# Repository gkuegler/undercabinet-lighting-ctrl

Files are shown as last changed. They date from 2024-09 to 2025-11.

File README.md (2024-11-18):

<!-- | Supported Targets | ESP32 | ESP32-C2 | ESP32-C3 | ESP32-C6 | ESP32-H2 | ESP32-P4 | ESP32-S2 | ESP32-S3 | -->
<!-- | ----------------- | ----- | -------- | -------- | -------- | -------- | -------- | -------- | -------- | -->
| Supported Targets: | ESP32 | ESP32-S3 |
| --- | --- | --- |

Uses ESP-IDF v5.2

# Kitchen Under Cabinet Lighting Controller
This controller mounts upside down underneath kitchen cabinets enables the undercabinet lighting to be turned on/off with with wave of a hand.
This is the source code for a gesture activated lighting controller which utilizes a HC-SR04 ultrasonic distance sensor.

This controller is designed to be mounted upside down underneath kitchen cabinets. It's compatible with 12-24VDC LEDs.

# 3D Printed Case
The custom case was designed in OnShape. See the link below for the project file.
https://cad.onshape.com/documents/ef51b7b650ada663375a7fe6/w/94d192bce853b8bb4785d228/e/2ec3751c0459ca22265b7e29

## Folder contents

ESP-IDF projects are built using CMake. 

Below is short explanation of remaining files in the project folder.
```
├── CMakeLists.txt
├── components (project libraries, see ESP-IDF for info on components)
├── kicad (project files for custom PCB)
├── main
│   ├── CMakeLists.txt
│   └── main.cpp (entry point)
└── README.md
```

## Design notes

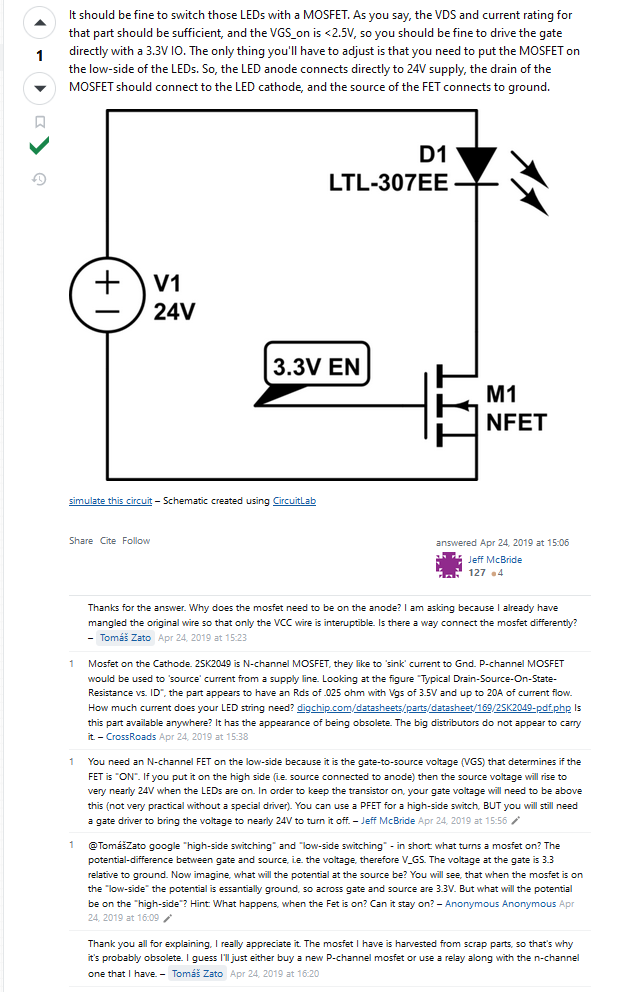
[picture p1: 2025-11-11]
design/n channel mosfet led switching.png

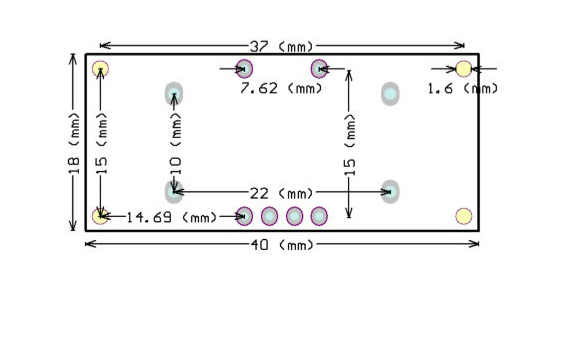
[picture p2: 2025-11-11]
design/Ultrasonic RCWL Dimensions.png

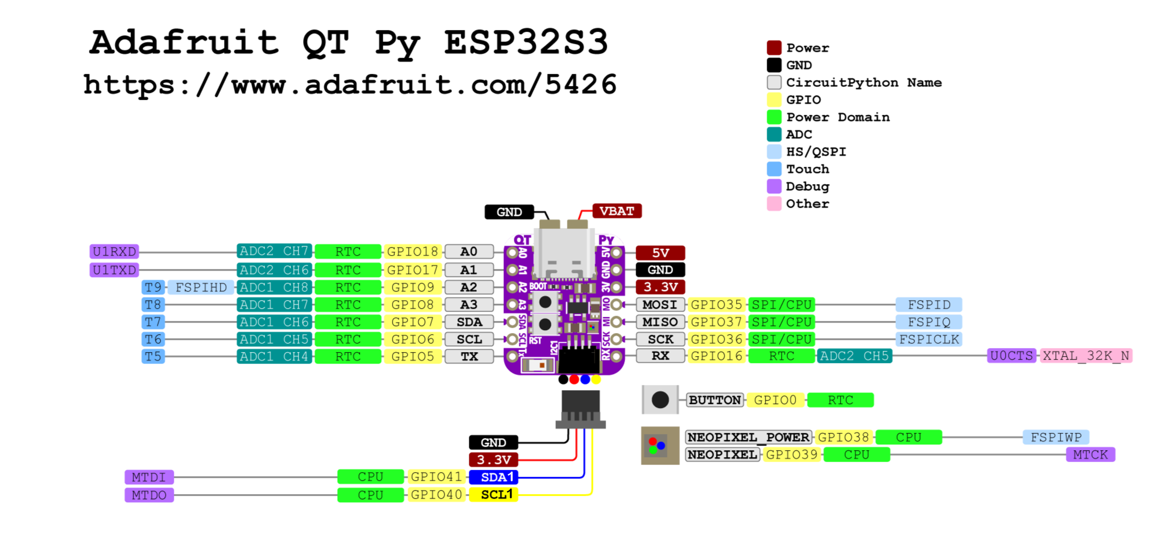
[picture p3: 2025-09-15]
design/Pinout Adafruit QTPy ESP32-S3.png

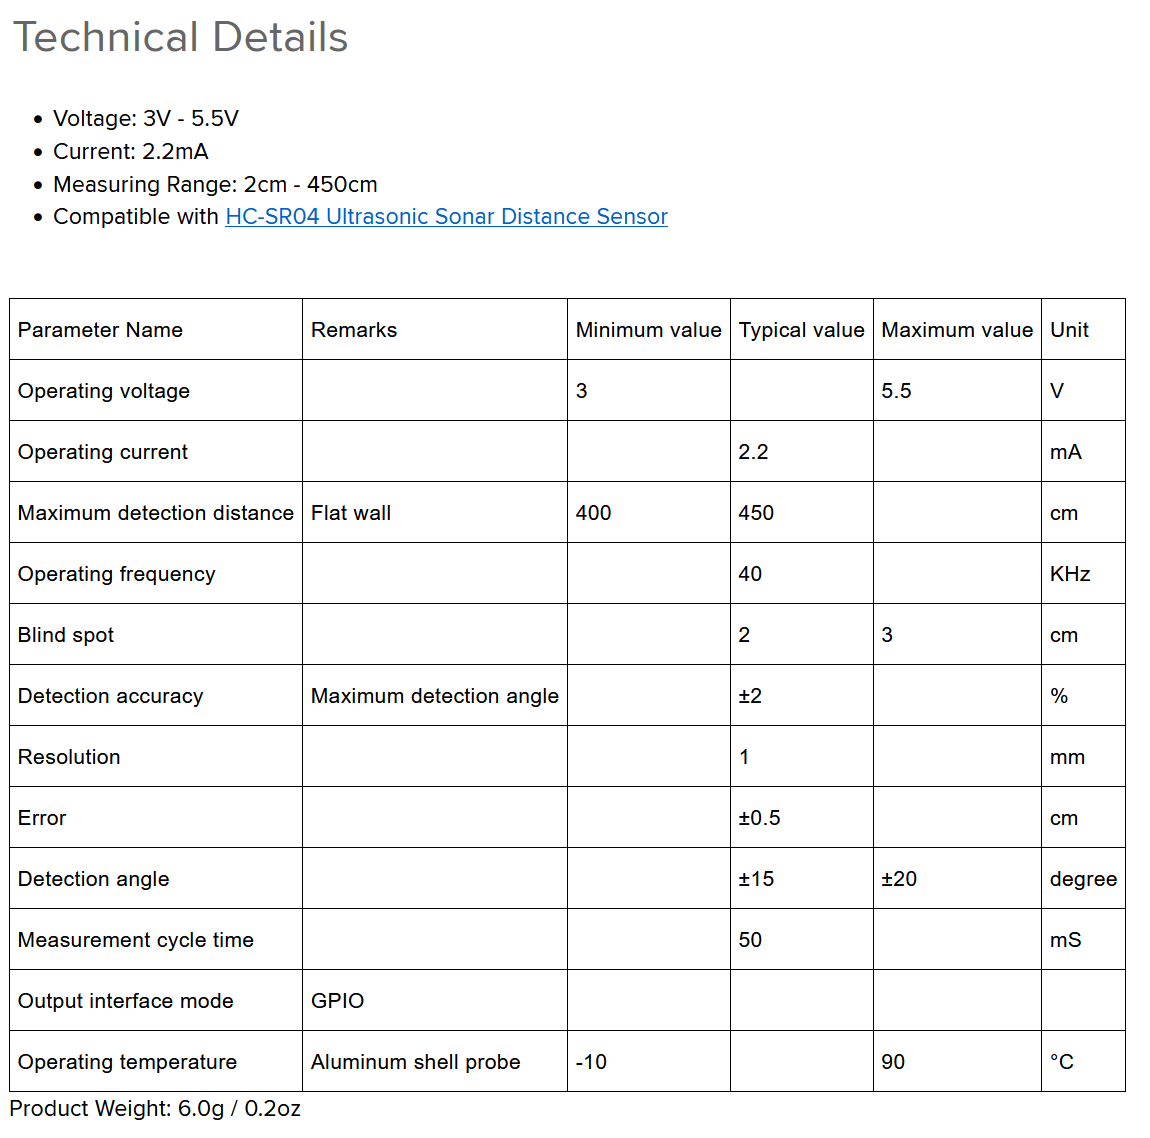
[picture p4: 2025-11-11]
design/Ultrasonic RCWL Specs.png

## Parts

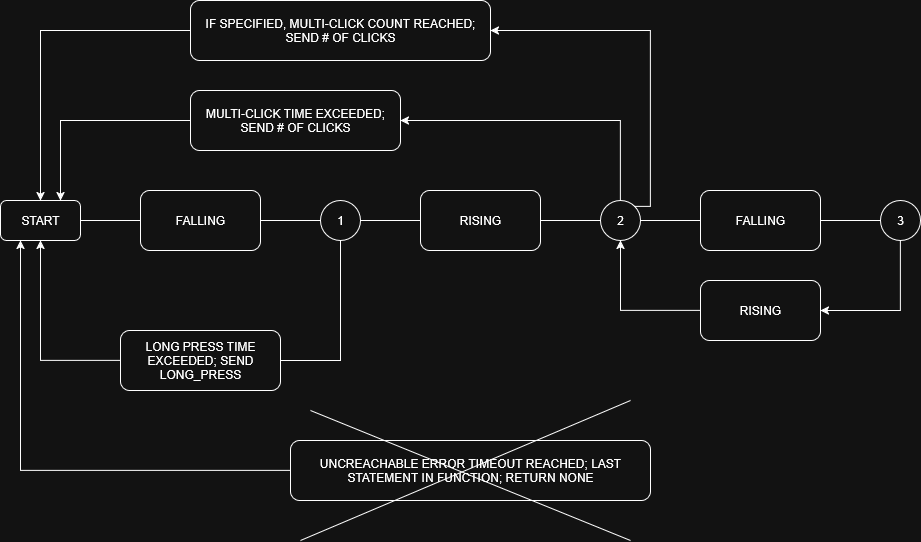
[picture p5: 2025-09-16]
components/debounce/button state machine.drawio.png

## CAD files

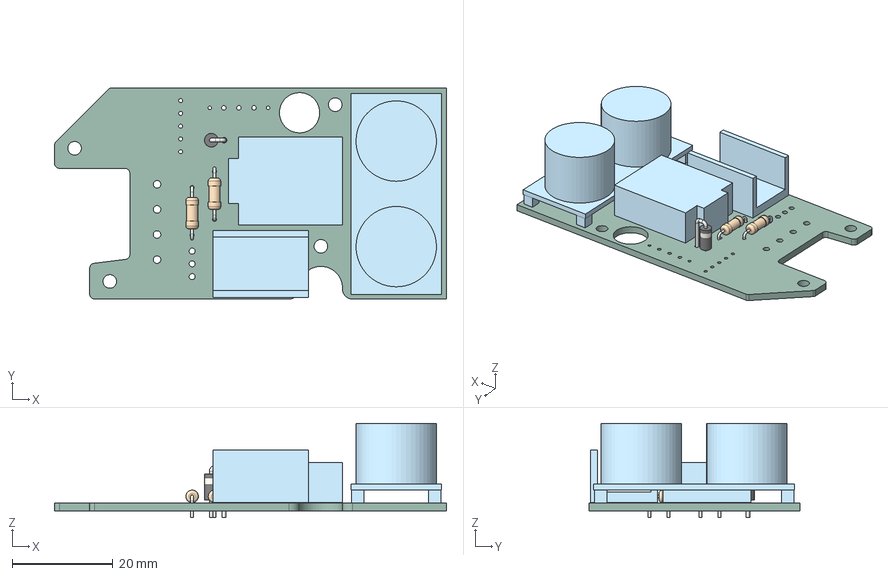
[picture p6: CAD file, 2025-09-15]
kicad/cablight-project v2.step
78.0 x 42.0 x 18.8 mm
R_Axial_DIN0207_L6.3mm_D2.5mm_P10.16mm_Horizontal x 2
QTPy
RCWL-1601
D_DO-41_SOD81_P2.54mm_Vertical_KathodeUp
TO-22-Heatsink
cablight-project_PCB

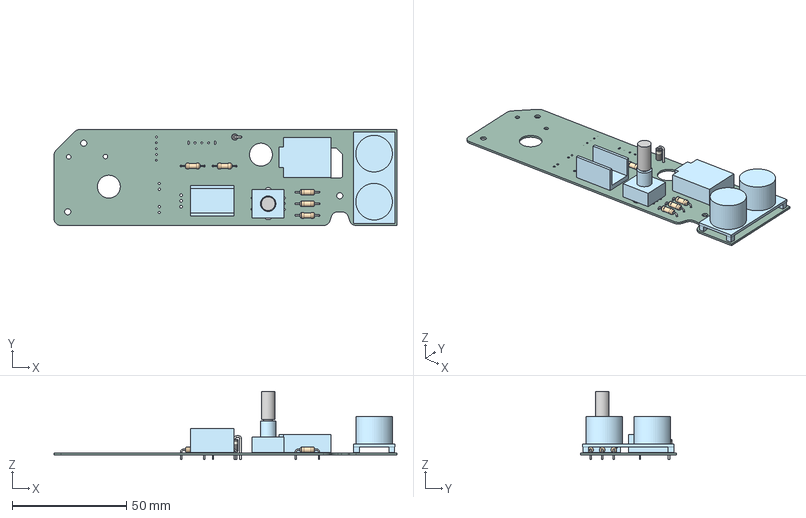
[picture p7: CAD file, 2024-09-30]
kicad/cablight-project/cablight-project.step
150.0 x 42.0 x 29.8 mm
R_Axial_DIN0207_L63mm_D25mm_P1016mm_Horizontal x 5
D_DO-41_SOD81_P2.54mm_Vertical_KathodeUp
cablight_PCB

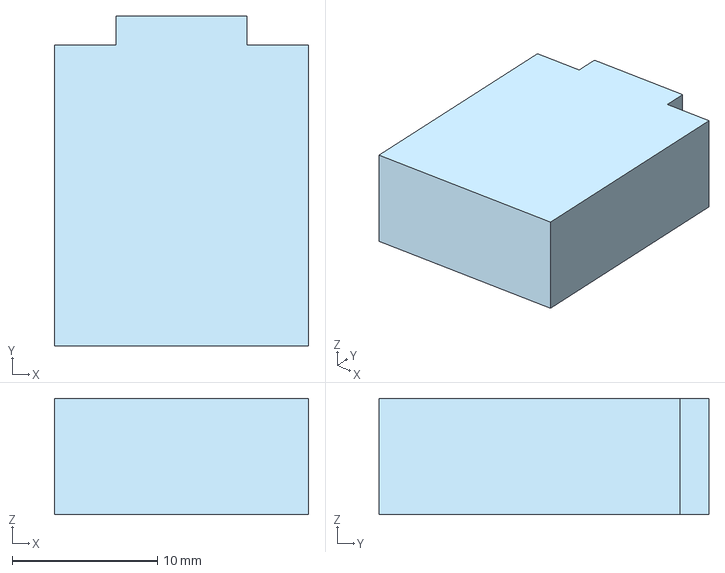
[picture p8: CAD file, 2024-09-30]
kicad/cablight-project/external part symbols, footprints & step files/Adafruit-QT-Py-ESP32-S3-PCB-main/QTPy.step
17.5 x 22.7 x 8.00 mm

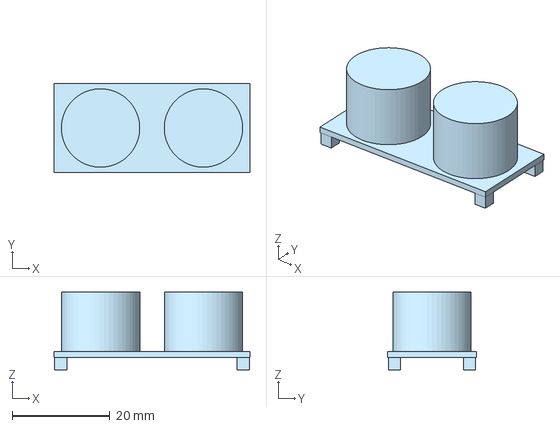
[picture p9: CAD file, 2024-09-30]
kicad/cablight-project/external part symbols, footprints & step files/RCWL-1601.step
40.0 x 18.1 x 15.8 mm

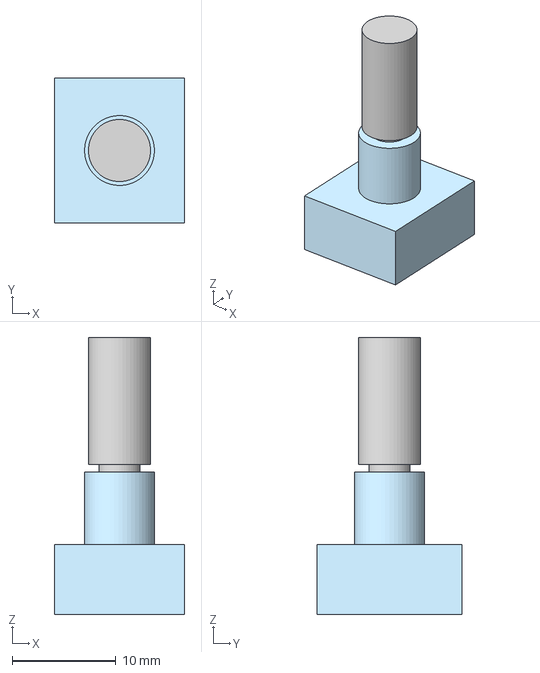
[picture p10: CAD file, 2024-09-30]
kicad/cablight-project/external part symbols, footprints & step files/rotary-encoder-PEC11R footprint/PEC11-20mm.step
12.6 x 14.0 x 26.8 mm

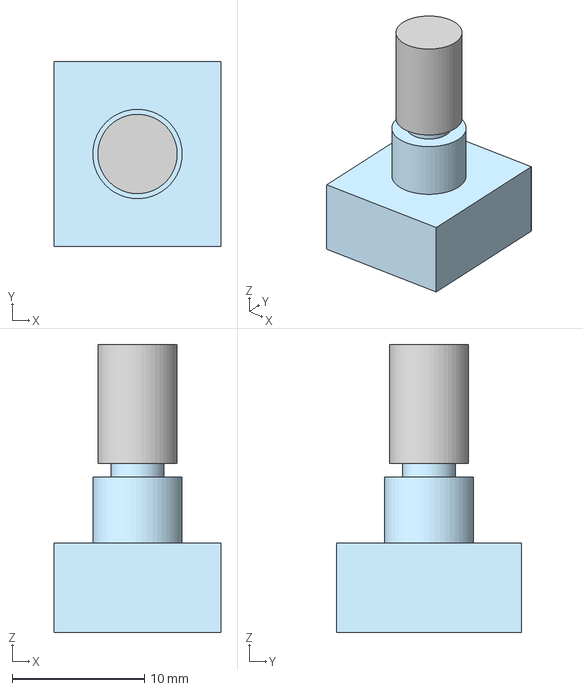
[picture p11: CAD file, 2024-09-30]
kicad/cablight-project/external part symbols, footprints & step files/rotary-encoder-PEC11R footprint/PEC11-15mm.step
12.6 x 14.0 x 21.8 mm

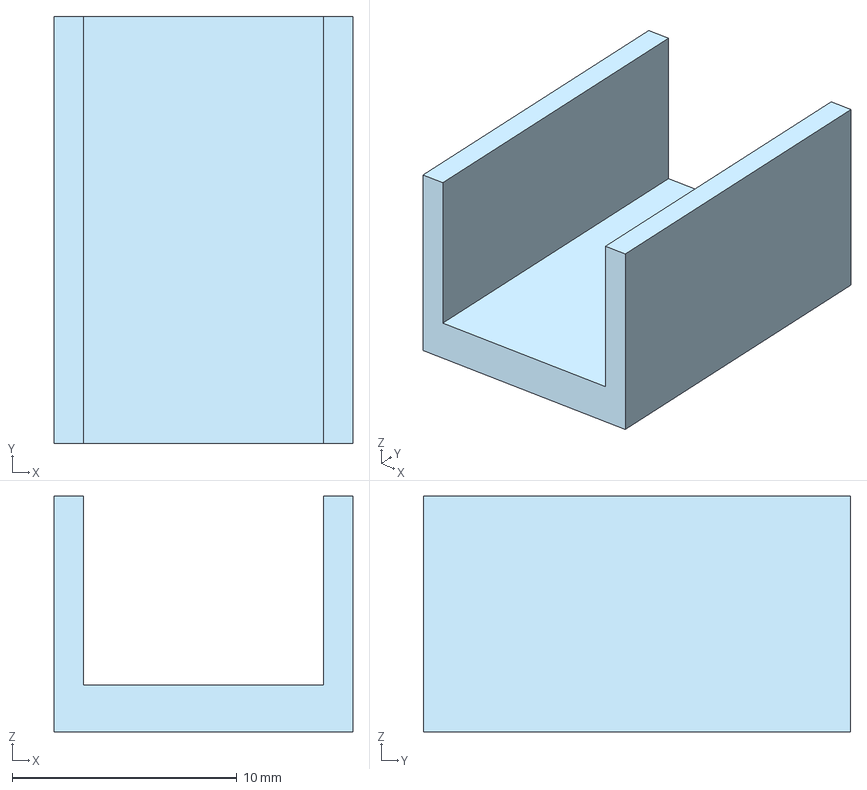
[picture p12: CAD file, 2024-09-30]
kicad/cablight-project/external part symbols, footprints & step files/TO-22-Heatsink.step
13.3 x 19.0 x 10.5 mm

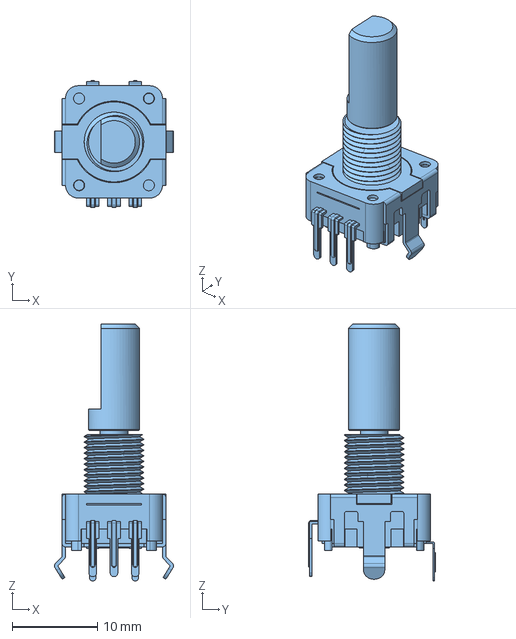
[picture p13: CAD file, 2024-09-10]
kicad/cablight-project/external part symbols, footprints & step files/rotary-encoder-PEC11R footprint/Bourns_-_PEC11R-4220F-S0024.step
14.0 x 14.9 x 30.2 mm

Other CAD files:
kicad/polycase option/C-0602.dwg
kicad/polycase option/BF-060210.dwg
kicad/cablight-project v2.stl

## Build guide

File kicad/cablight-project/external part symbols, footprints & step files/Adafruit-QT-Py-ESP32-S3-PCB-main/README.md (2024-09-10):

## Adafruit QT Py ESP32-S3 WiFi Dev Board PCB

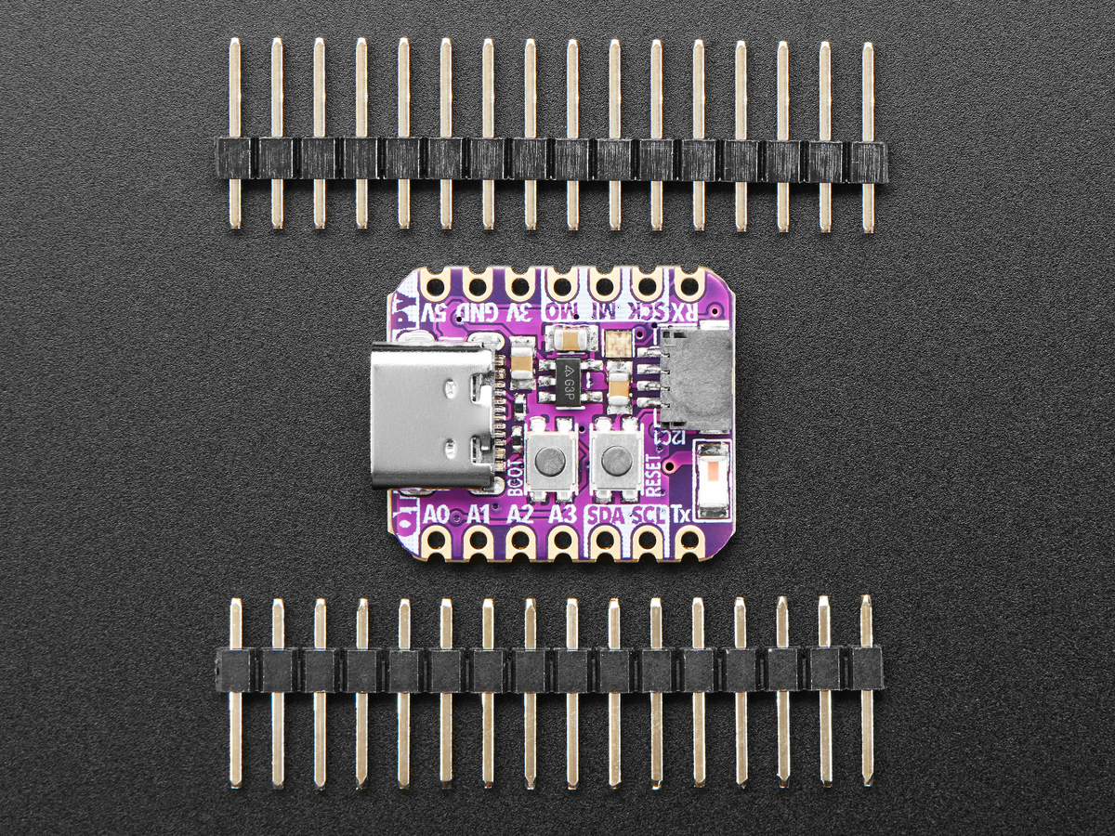
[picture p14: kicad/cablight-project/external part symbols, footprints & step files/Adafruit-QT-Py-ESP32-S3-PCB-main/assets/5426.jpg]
<a href="http://www.adafruit.com/products/5426"><br/>
Click here to purchase one from the Adafruit shop</a>

PCB files for the Adafruit QT Py ESP32-S3 WiFi Dev Board. 

Format is EagleCAD schematic and board layout
* https://www.adafruit.com/product/5426

### Description

The ESP32-S3 has arrived in QT Py format - and what a great way to get started with this powerful new chip from Espressif! With dual 240 MHz cores, WiFi and BLE support, and native USB, this QT Py is great for powering your IoT projects.

The ESP32-S3 is a highly-integrated, low-power, 2.4 GHz Wi-Fi System-on-Chip (SoC) solution that now has WiFi and BLE support, built-in native USB as well as some other interesting new technologies like Time of Flight distance measurements. With its state-of-the-art power and RF performance, this SoC is an ideal choice for a wide variety of application scenarios relating to the Internet of Things (IoT), wearable electronics, and smart homes. 

With native USB and 8 MB Flash this board will let you upgrade your existing ESP32 projects. Native USB means it can act like a keyboard or a disk drive, and no external USB-to-Serial converter required. WiFi and BLE mean it's awesome for IoT projects.

OLEDs! Inertial Measurement Units! Sensors a-plenty. All plug-and-play thanks to the innovative chainable design: SparkFun Qwiic-compatible STEMMA QT connectors for the I2C bus so you don't even need to solder! Just plug in a compatible cable and attach it to your MCU of choice, and you’re ready to load up some software and measure some light. Seeed Grove I2C boards will also work with this adapter cable.

Pinout and shape are Seeed Xiao compatible, with castellated pads so you can solder it flat to a PCB. In addition to the QT connector, we also added an RGB NeoPixel (with controllable power pin to allow for ultra-low-power usage), a reset button (great for restarting your program or entering the bootloader), and a button on GPIO 0 for entering the ROM bootloader or for user input

The ESP32-S3 has a dual-core 240 MHz chip, so it is comparable to ESP32's dual-core. However, there is no Bluetooth Classic support, only Bluetooth LE. This chip is a great step up from the earlier ESP32-S2! This ESP32-S3 chip we are using on the QT Py comes with 8 MB flash and no PSRAM, but it does have 512KB of SRAM so its fine for use with CircuitPython support as long as massive buffers are not needed. It's also great for use in ESP-IDF or with Arduino support.

* Same size, form-factor, and pin-out as Seeed Xiao
* USB Type C connector - If you have only Micro B cables, this adapter will come in handy!
* ESP32-S3 Dual Core 240MHz Tensilica processor - the next generation of ESP32-Sx, with native USB so it can act like a keyboard/mouse, MIDI device, disk drive, etc!
* Comes with 8MB Flash, 512KB SRAM, no PSRAM
* Native USB supported by every OS - can be used in Arduino or CircuitPython as USB serial console, MIDI, Keyboard/Mouse HID, even a little disk drive for storing Python scripts.
* Can be used with Arduino IDE or CircuitPython
* Built-in RGB NeoPixel LED with power control to reduce quiescent power in deep sleep
* Battery input pads on underside with diode protection for external battery packs up to 6V input
* 13 GPIO pins:
    * 11 on breakout pads, 2 more on QT connector
    * 10 x 12-bit analog inputs (SPI high speed pads do not have analog inputs)
    * PWM outputs on any pin
    * Two I2C ports, one on the breakout pads, and another with STEMMA QT plug-n-play connector
    * Hardware UART
    * Hardware SPI on the high speed SPI peripheral pins
    * Hardware I2S on any pins
    * 5 x Capacitive Touch with no additional components required
* 3.3V regulator with 600mA peak output
* Light sleep at 2~4mA, deep sleep at ~70uA
* Reset switch for starting your project code over, boot 0 button for entering bootloader mode
* Really really small

### License

Adafruit invests time and resources providing this open source design, please support Adafruit and open-source hardware by purchasing products from [Adafruit](https://www.adafruit.com)!

Designed by Limor Fried/Ladyada for Adafruit Industries.

Creative Commons Attribution/Share-Alike, all text above must be included in any redistribution. 
See license.txt for additional details.

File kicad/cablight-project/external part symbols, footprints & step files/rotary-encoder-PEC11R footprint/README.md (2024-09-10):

# Adafruit's PEC11R-4220F-S0024 Rotary encoder for KiCAD

### How to use this footprint
1. Download .zip file containing this repository's contents
2. Open the footprint editor



3. Right click on the in the footprint tree explorer and choose import footprint



4. Choose the edit footprint properties icon



5. Open the 3D models option in the edit footprint properties modal



6. Choose the "+" icon to add a new 3D model
7. Select the .step file downloaded from this repository
8. Validate the model's fitment on the footprint



9. Save footprint in the desired library



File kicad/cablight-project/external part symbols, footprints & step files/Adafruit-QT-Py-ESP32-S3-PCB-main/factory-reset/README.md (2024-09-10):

## Factory Reset file - QT ESP32-S3 WiFi Dev Board

This is the factory reset file for the QT ESP32-S3 WiFi Dev Board.

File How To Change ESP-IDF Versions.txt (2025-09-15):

1. Use express install for "workspace folder" to install ver version.
File hierarchy:

L:\Espressif
└──idf_v5.5.1  (make this folder for each version)
    ├── idf              (make this folder, choose as idf location)
    └── tools            (make this folder, choose as toolchain folder)

2.
a. Use a project sample to generate the required .vscode folder files.
b. ESP_IDF: Add VSCode Configuration folder (will add settings.json & launch.json)

--- settings.josn ---
Use options at bottom to select:
    - flashing method
    - com port
    - openocd target board (IDF_TARGET)

--- c_cpp_properties.json ---

Set this to the current toolchain version compiler (this will prevent include sq):
"compilerPath": "${config:idf.toolsPathWin}\\tools\\xtensa-esp-elf\\esp-14.2.0_20241119\\xtensa-esp-elf\\bin\\xtensa-esp32s3-elf-gcc.exe",

Add compiler commands:
"compileCommands": ["${workspaceFolder}/build/compile_commands.json"],

# Debugging
Download Zadig tool (Zadig_X.X.exe) from https://zadig.akeo.ie/ and run it.
Set (Interface 1) to libusbk. Don't touch (Interface 0 is serial port).
If I need to reset the driver for the serial port. Go to Device Manager. THen USB devices and update driver.

Set Adapter Speed in esp jtag config file in toolchain folder:
adapter speed 20000

In Zadig tool go to Options and check List All Devices.

Check the list of devices that should contain two specific USB entries:  (Interface 0) and  (Interface 1).

The first device ( (Interface 0)) is connected to the JTAG port of the ESP32. Original driver of this device should be replaced with WinUSB (v6xxxxx).

Note: Do not change the second device (Interface 1). It is routed to ESP32's serial port (UART) used for upload of application to ESP32's flash.

There are two versions of this board: 4MB Flash/2MB PSRAM or 8MB Flash/No PSRAM
I have (2) of the 4MB Flash/2MB PSRAM for the smaller QTPy's.

Make sure
"idf.openOcdDebugLevel": 1,
If it is set too high (like 4) things will take too long and it will error out.

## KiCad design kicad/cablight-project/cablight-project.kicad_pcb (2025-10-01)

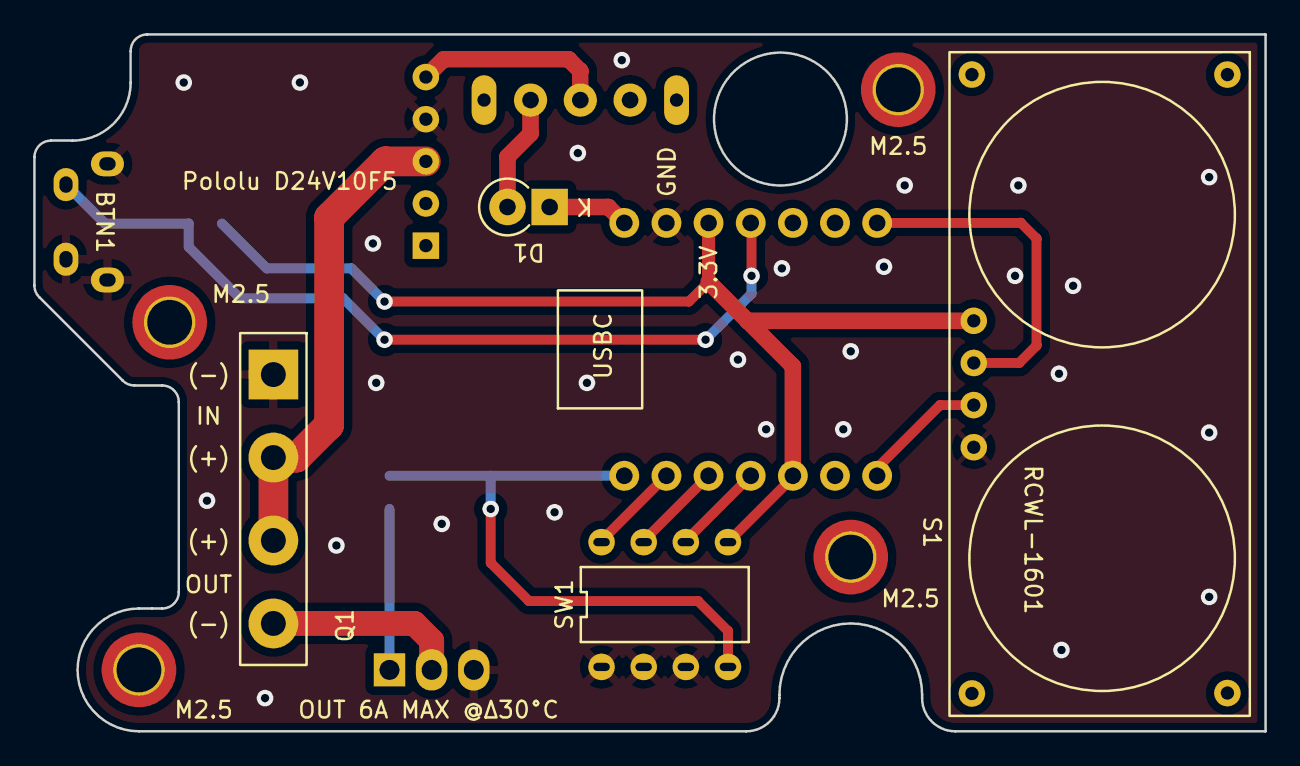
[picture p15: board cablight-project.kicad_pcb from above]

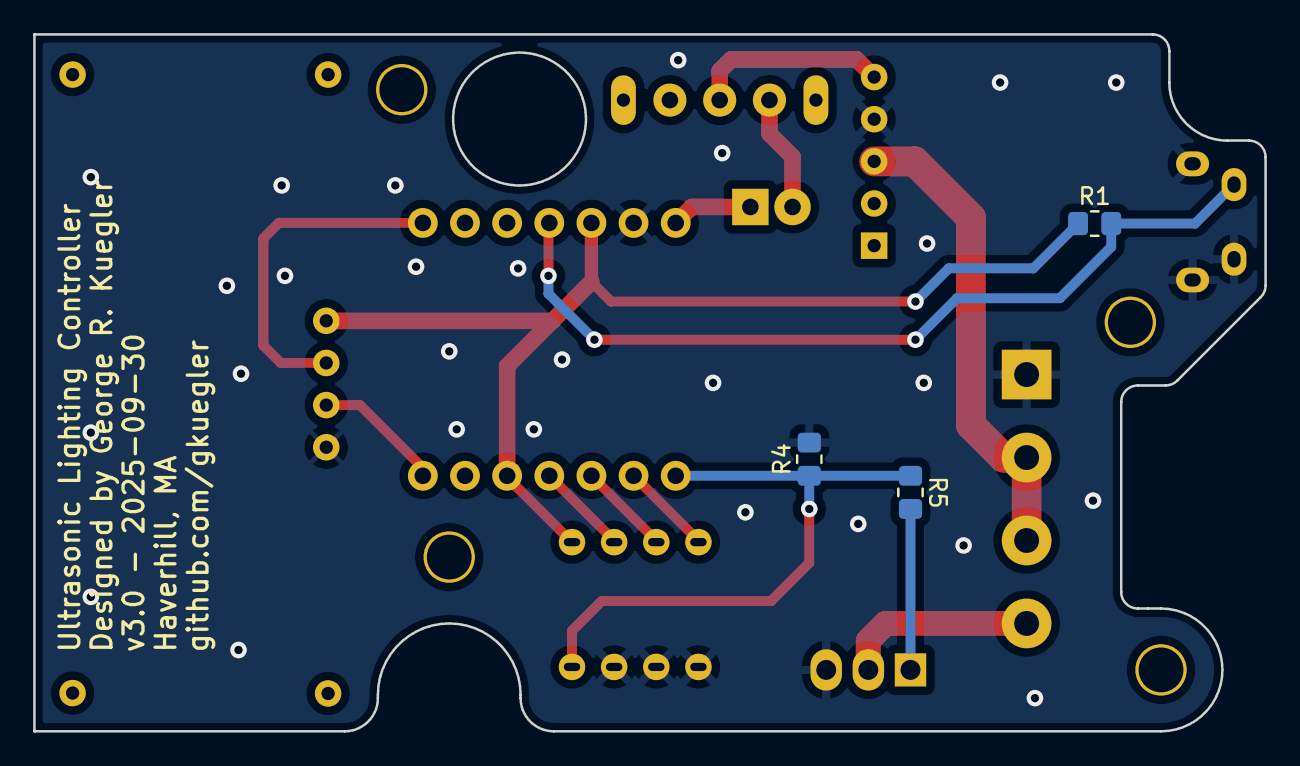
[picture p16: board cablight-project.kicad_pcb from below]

Board: 2 copper layers, 74.2 x 42.0 mm, 16 parts (3 on the bottom side), 15 nets.

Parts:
BTN1: SW_Push; Tactile Switch Wurth
D1: 1N5817; D_DO-41_SOD81_P2.54mm_Vertical_KathodeUp
J3: Screw_Term_1x4_5mm; Molex 4pin Terminal Block
M2.5, M2.5#2, M2.5#3, M2.5#4: MountingHole_2.7mm_M2.5_ISO7380_Pad_TopOnly
P1: Pololu D24V10F5; Pololu_5V_H
Q1: IRLB8721PBF; TO-220F-3_H_Heatsink
R1: 10k; R_0805_2012Metric_Pad1.20x1.40mm_HandSolder
R4: 10K; R_0805_2012Metric_Pad1.20x1.40mm_HandSolder
R5: 47R; R_0805_2012Metric_Pad1.20x1.40mm_HandSolder
S1: RCWL-1601
SW1: SW_DIP_x04; DIP-4 DS04-254 SAME SKY
SW3: switch_SPDT_SLW_121586; Switch_SPDT_CUI_500mA_3mm
U1: AdafruitQTPyEsp32S3

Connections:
/5V_MCU: D1.1 (K), U1.14 (5V)
/5V_sw: D1.2 (A), SW3.2
/+5V: P1.5 (VOUT_5V), SW3.1
/+24V: J3.2, J3.3, P1.3 (VIN_24V)
/LED-: J3.4, Q1.2 (D)
/SRO4 PWR: R1.1, S1.1 (Vin), SW1.5, U1.5 (GPIO_7), U1.12 (3.3V)
/echo: S1.3 (Echo), U1.7 (GPIO_5)
/trig: S1.2 (Trig), U1.8 (GPIO_16)
<NO NET>: BTN1.2, BTN1.GND, J3.1, P1.4 (GND), Q1.3 (S), R4.2, S1.4 (GND), SW1.1, SW1.2, SW1.3, U1.13 (GND)
unnamed: Q1.1 (G), R5.2
unnamed: SW1.6, U1.4 (GPIO_8)
unnamed: SW1.7, U1.3 (GPIO_9)
unnamed: SW1.8, U1.2 (GPIO_17)
unnamed: R4.1, R5.1, SW1.4, U1.1 (GPIO_18)
unnamed: BTN1.1, R1.2, U1.11 (GPIO_35)

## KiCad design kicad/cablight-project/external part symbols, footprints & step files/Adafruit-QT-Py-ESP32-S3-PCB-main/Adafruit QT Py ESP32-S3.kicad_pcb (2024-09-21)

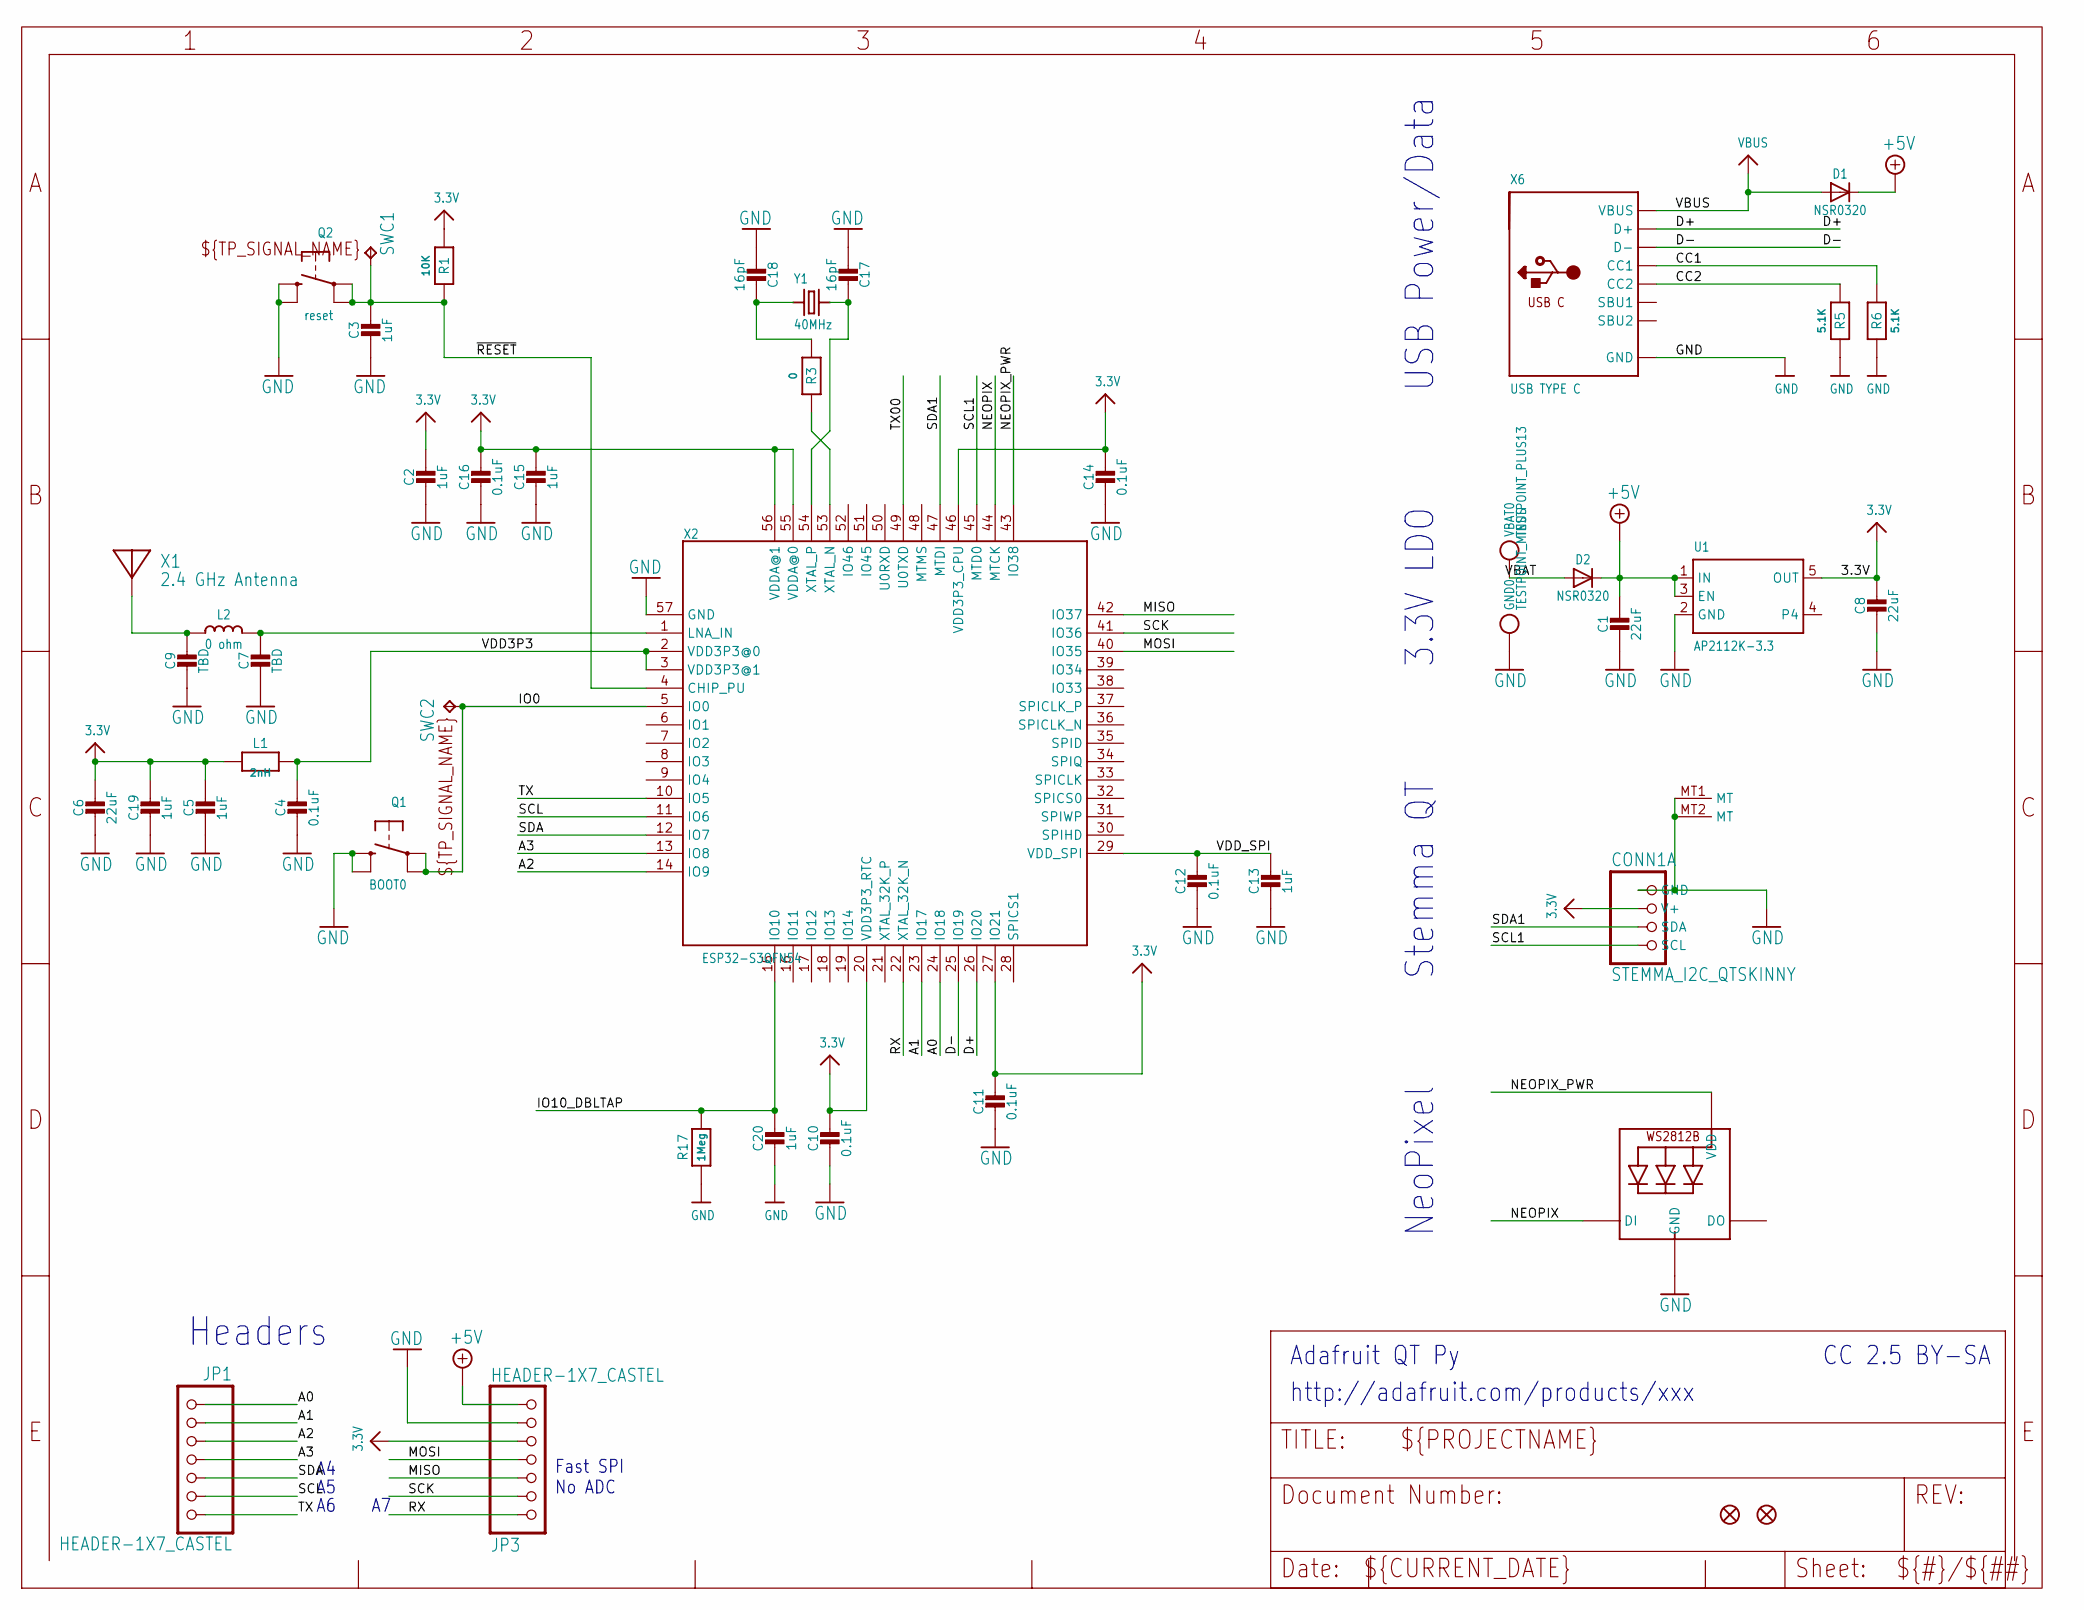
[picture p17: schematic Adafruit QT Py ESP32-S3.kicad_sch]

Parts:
C1, C6, C8: 22uF; 0805-NO
C2, C3, C5, C13, C15, C19, C20: 1uF; _0402NO
C4, C10, C11, C12, C14, C16: 0.1uF; _0402NO
C7, C9: TBD; _0402NO
C17, C18: 16pF; _0402NO
CONN1: STEMMA_I2C_QTSKINNY; JST_SH4_SKINNY
D1, D2: NSR0320; SOD-323_MINI
GND0: TESTPOINT_MINUS; TESTPOINT_MINUS_1X3MM
JP1, JP3: HEADER-1X7_CASTEL; 1X07_CASTEL
L1: 2nH; _0402NO
L2: 0 ohm; _0402
LED1: WS2812B_SK6805_1515; SK6805_1515
Q1: BOOT0; BTN_KMR2_4.6X2.8
Q2: reset; BTN_KMR2_4.6X2.8
R1: 10K; _0402NO
R3: 0; _0402NO
R5, R6: 5.1K; _0402NO
R17: 1Meg; _0402NO
SWC1, SWC2: TPB1,27; B1,27
U1: AP2112K-3.3; SOT23-5
U$6, U$8: FIDUCIAL_1MM
VBAT0: TESTPOINT_PLUS13; TESTPOINT_PLUS_1X3MM
X1: 2.4 GHz Antenna; ANT_2450AT18B100
X2: ESP32-S3QFN54; QFN56_7X7
X6: USB TYPE C; USB_C_CUSB31-CFM2AX-01-X
Y1: 40MHz; CRYSTAL_2X1.6

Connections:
3.3V: C2.1, C5.1, C6.1, C8.1, C10.1, C11.1, C14.1, C15.1, C16.1, C19.1, CONN1.2 (V+), JP3.5, JP3.5C (5), L1.1, R1.1, U1.5 (OUT), X2.20 (VDD3P3_RTC), X2.27 (IO21), X2.46 (VDD3P3_CPU), X2.55 (VDDA@0), X2.56 (VDDA@1)
+5V: C1.1, D1.C, D2.C, JP3.7, JP3.7C (7), U1.1 (IN), U1.3 (EN)
A0: JP1.1, JP1.1C (1), X2.24 (IO18)
A1: JP1.2, JP1.2C (2), X2.23 (IO17)
A2: JP1.3, JP1.3C (3), X2.14 (IO9)
A3: JP1.4, JP1.4C (4), X2.13 (IO8)
CC1: R6.2, X6.A5 (CC1)
CC2: R5.2, X6.B5 (CC2)
D+: X2.26 (IO20), X6.A6 (D+), X6.B6 (D+)
D-: X2.25 (IO19), X6.A7 (D-), X6.B7 (D-)
GND: C1.2, C2.2, C3.2, C4.2, C5.2, C6.2, C7.2, C8.2, C9.2, C10.2, C11.2, C12.2, C13.2, C14.2, C15.2, C16.2, C17.2, C18.2, C19.2, C20.2, CONN1.1 (GND), CONN1.MT1 (MT), CONN1.MT2 (MT), GND0.P$1, JP3.6, JP3.6C (6), LED1.4 (GND), Q1.B (S), Q1.B' (S1), Q2.B (S), Q2.B' (S1), R5.1, R6.1, R17.1, U1.2 (GND), X2.57 (GND), X6.A1B12 (GND), X6.B1A12 (GND)
IO0: Q1.A, Q1.A' (P1), SWC2.TP, X2.5 (IO0)
IO10_DBLTAP: C20.1, R17.2, X2.15 (IO10)
MISO: JP3.3, JP3.3C (3), X2.42 (IO37)
MOSI: JP3.4, JP3.4C (4), X2.40 (IO35)
unnamed: R3.2, X2.53 (XTAL_N)
unnamed: C7.1, L2.2, X2.1 (LNA_IN)
unnamed: C9.1, L2.1, X1.FP
unnamed: C17.1, X2.54 (XTAL_P), Y1.3 (2)
unnamed: C18.1, R3.1, Y1.1
NEOPIX: LED1.1 (DI), X2.44 (MTCK)
NEOPIX_PWR: LED1.2 (VDD), X2.43 (IO38)
RX: JP3.1, JP3.1C (1), X2.22 (XTAL_32K_N)
SCK: JP3.2, JP3.2C (2), X2.41 (IO36)
SCL: JP1.6, JP1.6C (6), X2.11 (IO6)
SCL1: CONN1.4 (SCL), X2.45 (MTD0)
SDA: JP1.5, JP1.5C (5), X2.12 (IO7)
SDA1: CONN1.3 (SDA), X2.47 (MTDI)
TX: JP1.7, JP1.7C (7), X2.10 (IO5)
TX00: X2.49 (U0TXD)
VBAT: D2.A, VBAT0.P$1
VBUS: D1.A, X6.A4B9 (VBUS), X6.B4A9 (VBUS)
VDD3P3: C4.1, L1.2, X2.2 (VDD3P3@0), X2.3 (VDD3P3@1)
VDD_SPI: C12.1, C13.1, X2.29 (VDD_SPI)
~RESET: C3.1, Q2.A, Q2.A' (P1), R1.2, SWC1.TP, X2.4 (CHIP_PU)

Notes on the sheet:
USB Power/Data
CC 2.5 BY-SA
Fast SPI No ADC
NeoPixel
Stemma QT
Adafruit QT Py
Headers
http://adafruit.com/products/xxx
3.3V LDO

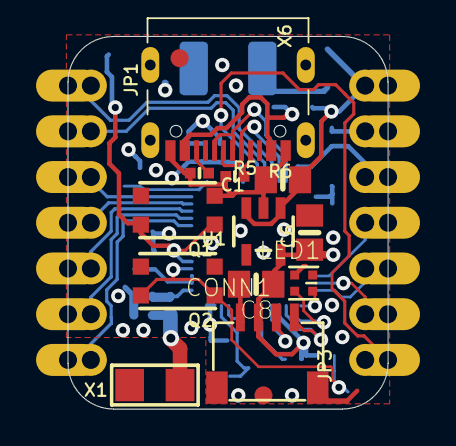
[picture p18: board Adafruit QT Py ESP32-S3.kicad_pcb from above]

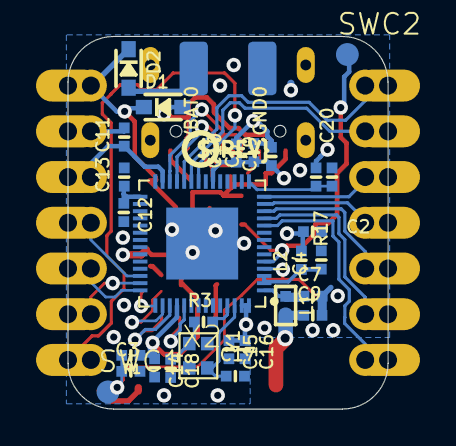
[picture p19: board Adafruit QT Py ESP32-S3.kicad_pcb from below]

Board: 4 copper layers, 17.8 x 20.7 mm, 49 parts (32 on the bottom side), 34 nets.

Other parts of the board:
U$7: QTPY_ESP32_TOP
U$11: QTPYS3_BOT
U$12: PCBFEAT-REV-040

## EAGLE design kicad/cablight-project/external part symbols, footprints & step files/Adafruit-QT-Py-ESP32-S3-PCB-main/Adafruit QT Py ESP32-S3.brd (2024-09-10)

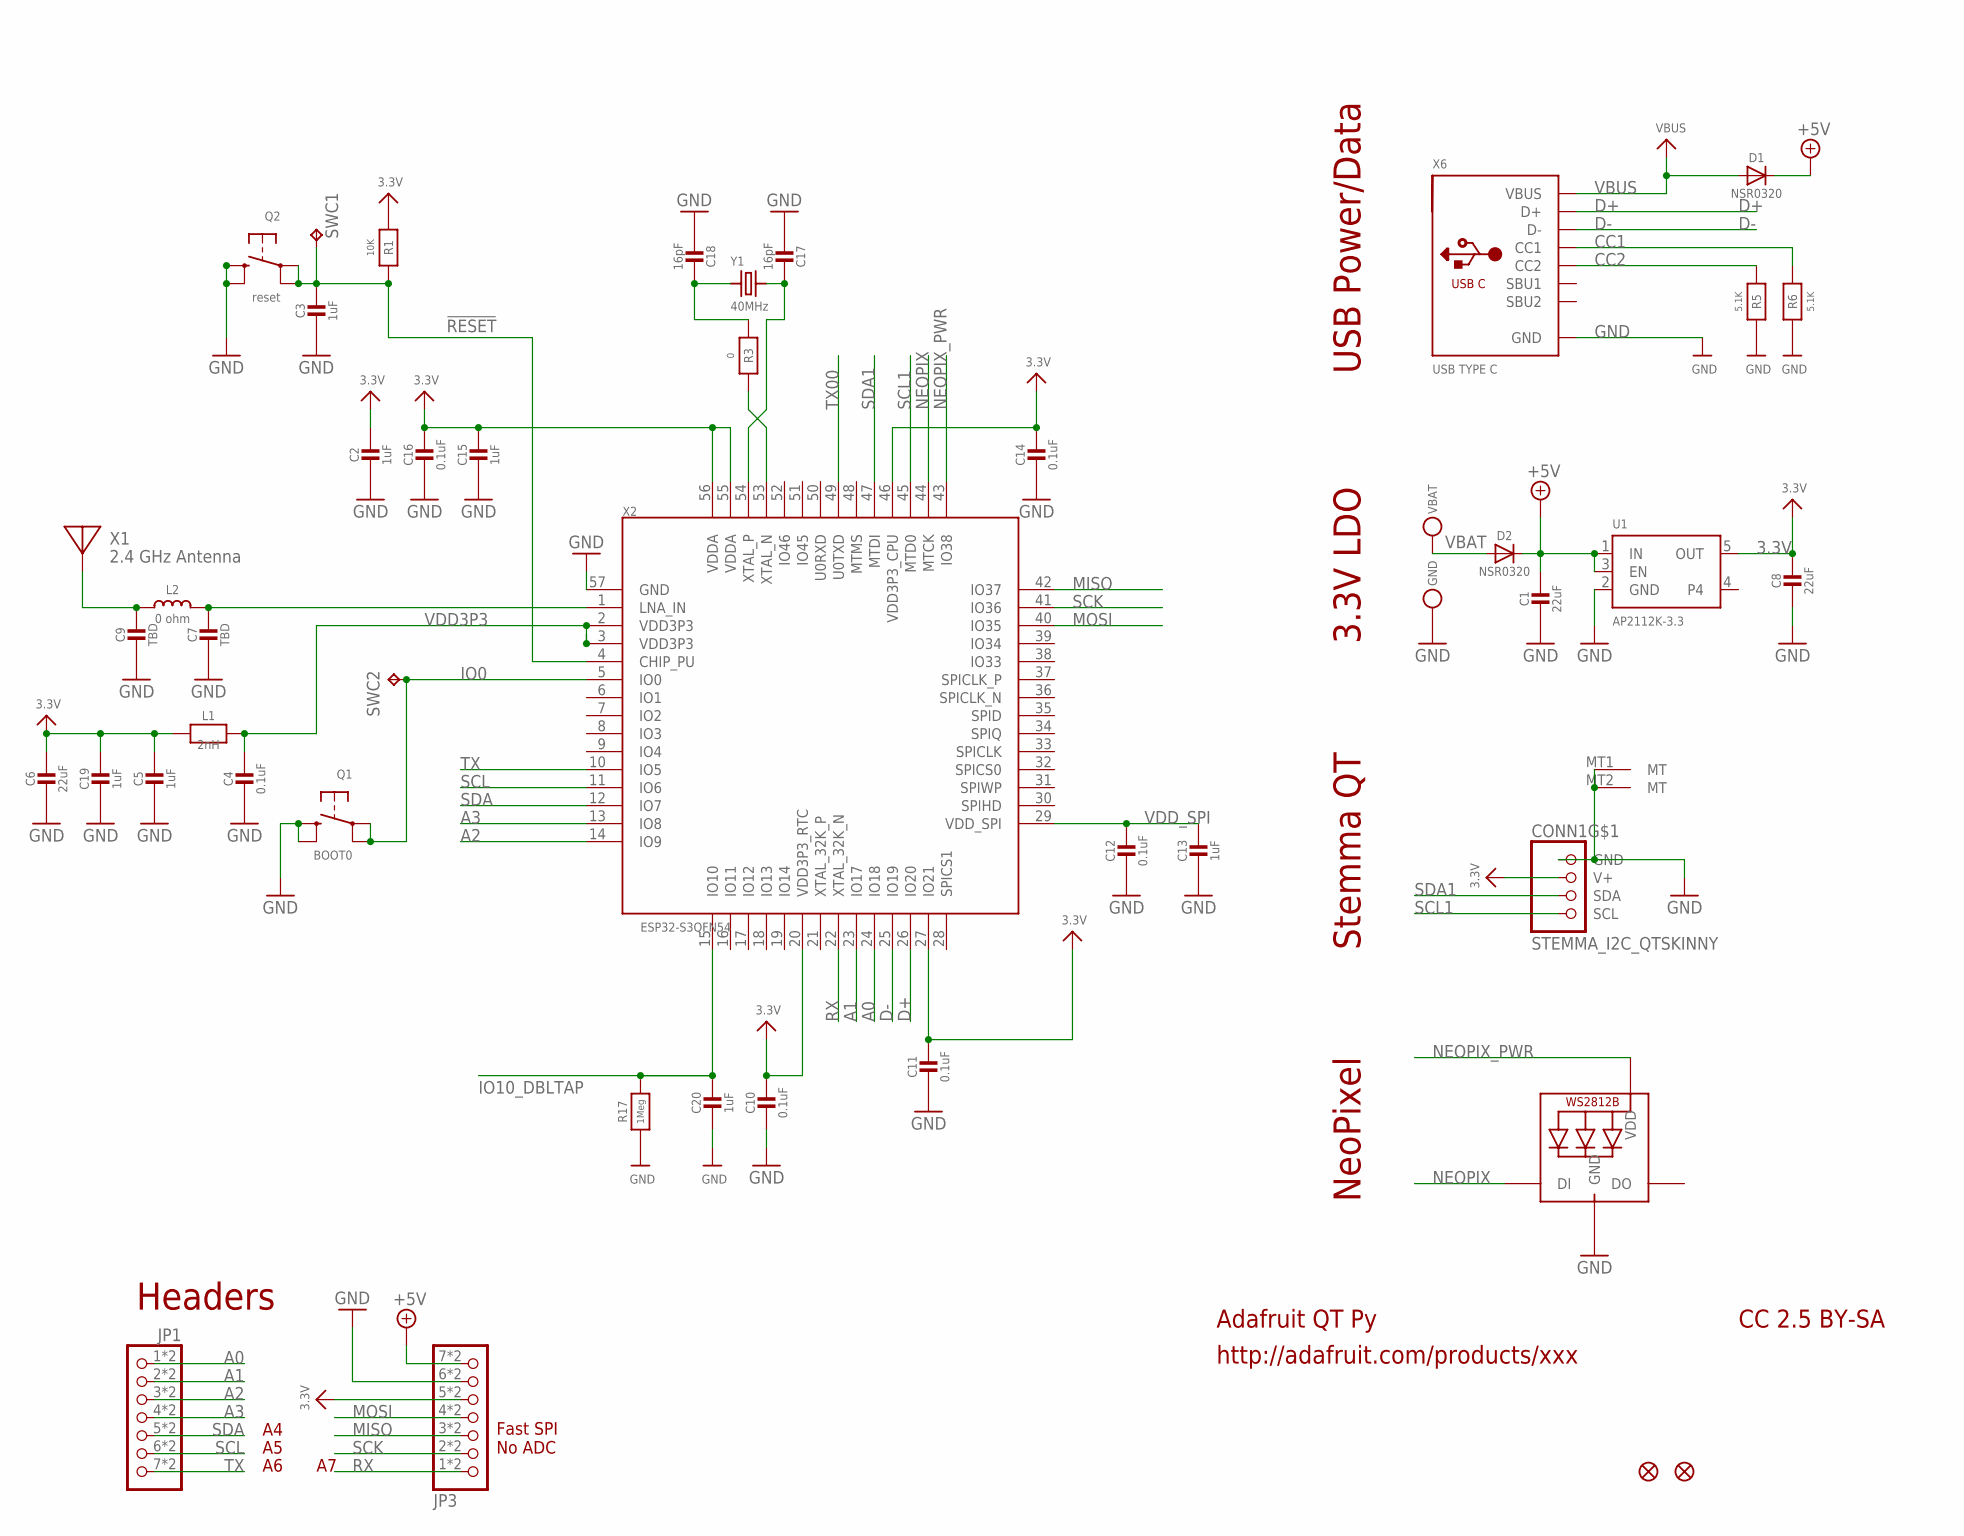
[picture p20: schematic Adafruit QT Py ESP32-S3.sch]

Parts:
C1, C6, C8: 22uF; 0805-NO
C2, C3, C5, C13, C15, C19, C20: 1uF; _0402NO
C4, C10, C11, C12, C14, C16: 0.1uF; _0402NO
C7, C9: TBD; _0402NO
C17, C18: 16pF; _0402NO
CONN1: STEMMA_I2C_QTSKINNY; JST_SH4_SKINNY
D1, D2: NSR0320; SOD-323_MINI
GND: TESTPOINT_MINUS; TESTPOINT_MINUS_1X3MM
JP1, JP3: HEADER-1X7_CASTEL; 1X07_CASTEL
L1: 2nH; _0402NO
L2: 0 ohm; _0402
LED1: WS2812B_SK6805_1515; SK6805_1515
Q1: BOOT0; BTN_KMR2_4.6X2.8
Q2: reset; BTN_KMR2_4.6X2.8
R1: 10K; _0402NO
R3: 0; _0402NO
R5, R6: 5.1K; _0402NO
R17: 1Meg; _0402NO
SWC1, SWC2: TPB1,27; B1,27
U1: AP2112K-3.3; SOT23-5
U$6, U$8: FIDUCIAL_1MM
VBAT: TESTPOINT_PLUS13; TESTPOINT_PLUS_1X3MM
X1: 2.4 GHz Antenna; ANT_2450AT18B100
X2: ESP32-S3QFN54; QFN56_7X7
X6: USB TYPE C; USB_C_CUSB31-CFM2AX-01-X
Y1: 40MHz; CRYSTAL_2X1.6

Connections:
3.3V: C2.1, C5.1, C6.1, C8.1, C10.1, C11.1, C14.1, C15.1, C16.1, C19.1, CONN1.2 (V+), JP3.5, JP3.5C (5), L1.1, R1.1, U1.5 (OUT), X2.20 (VDD3P3_RTC), X2.27 (IO21), X2.46 (VDD3P3_CPU), X2.55 (VDDA), X2.56 (VDDA)
!RESET: C3.1, Q2.A, Q2.A' (P1), R1.2, SWC1.TP, X2.4 (CHIP_PU)
+5V: C1.1, D1.C, D2.C, JP3.7, JP3.7C (7), U1.1 (IN), U1.3 (EN)
A0: JP1.1, JP1.1C (1), X2.24 (IO18)
A1: JP1.2, JP1.2C (2), X2.23 (IO17)
A2: JP1.3, JP1.3C (3), X2.14 (IO9)
A3: JP1.4, JP1.4C (4), X2.13 (IO8)
CC1: R6.2, X6.A5 (CC1)
CC2: R5.2, X6.B5 (CC2)
D+: X2.26 (IO20), X6.A6 (D+), X6.B6 (D+)
D-: X2.25 (IO19), X6.A7 (D-), X6.B7 (D-)
GND: C1.2, C2.2, C3.2, C4.2, C5.2, C6.2, C7.2, C8.2, C9.2, C10.2, C11.2, C12.2, C13.2, C14.2, C15.2, C16.2, C17.2, C18.2, C19.2, C20.2, CONN1.1 (GND), CONN1.MT1 (MT), CONN1.MT2 (MT), GND.P$1, JP3.6, JP3.6C (6), LED1.4 (GND), Q1.B (S), Q1.B' (S1), Q2.B (S), Q2.B' (S1), R5.1, R6.1, R17.1, U1.2 (GND), X2.57 (GND), X6.A1B12 (GND), X6.B1A12 (GND)
IO0: Q1.A, Q1.A' (P1), SWC2.TP, X2.5 (IO0)
IO10_DBLTAP: C20.1, R17.2, X2.15 (IO10)
MISO: JP3.3, JP3.3C (3), X2.42 (IO37)
MOSI: JP3.4, JP3.4C (4), X2.40 (IO35)
unnamed: R3.2, X2.53 (XTAL_N)
unnamed: C7.1, L2.2, X2.1 (LNA_IN)
unnamed: C9.1, L2.1, X1.FP
unnamed: C17.1, X2.54 (XTAL_P), Y1.3 (2)
unnamed: C18.1, R3.1, Y1.1
NEOPIX: LED1.1 (DI), X2.44 (MTCK)
NEOPIX_PWR: LED1.2 (VDD), X2.43 (IO38)
RX: JP3.1, JP3.1C (1), X2.22 (XTAL_32K_N)
SCK: JP3.2, JP3.2C (2), X2.41 (IO36)
SCL: JP1.6, JP1.6C (6), X2.11 (IO6)
SCL1: CONN1.4 (SCL), X2.45 (MTD0)
SDA: JP1.5, JP1.5C (5), X2.12 (IO7)
SDA1: CONN1.3 (SDA), X2.47 (MTDI)
TX: JP1.7, JP1.7C (7), X2.10 (IO5)
TX00: X2.49 (U0TXD)
VBAT: D2.A, VBAT.P$1
VBUS: D1.A, X6.A4B9 (VBUS), X6.B4A9 (VBUS)
VDD3P3: C4.1, L1.2, X2.2 (VDD3P3), X2.3 (VDD3P3)
VDD_SPI: C12.1, C13.1, X2.29 (VDD_SPI)

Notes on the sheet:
Adafruit QT Py
http://adafruit.com/products/xxx
CC 2.5 BY-SA
NeoPixel
Stemma QT
3.3V LDO
USB Power/Data
Headers
Fast SPI No ADC

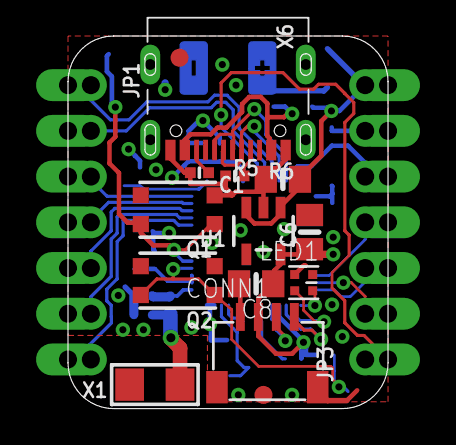
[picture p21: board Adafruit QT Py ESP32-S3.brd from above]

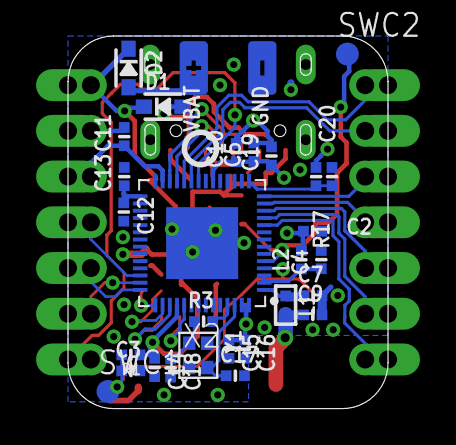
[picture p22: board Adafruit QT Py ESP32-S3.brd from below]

Board: 4 copper layers, 17.8 x 20.7 mm, 49 parts (32 on the bottom side), 34 nets.

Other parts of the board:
U$7: QTPY_ESP32_TOP
U$11: QTPYS3_BOT
U$12: PCBFEAT-REV-040

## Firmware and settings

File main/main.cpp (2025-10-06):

#include "inttypes.h"
#include <numeric>

#include "driver/gpio.h"
#include "esp_intr_alloc.h"
#include "esp_log.h"
#include "esp_timer.h"

#include "freertos/FreeRTOS.h"
#include "freertos/queue.h"
#include "freertos/task.h"

/*** LOCAL COMPONENT INCLUDES ***/
#include "debounce.hpp"
#include "ultrasonic.hpp"

/*** LOCAL INCLUDES ***/
#include "dipswitch.h"
#include "error.h"
#include "event.hpp"
#include "filter.hpp"
#include "led.hpp"
#include "mutex.hpp"
#include "parameters.h"
#include "ring-buffer.hpp"
#include "timer.hpp"

// TODO: make options with jumpers and/or wifi server
// TODO: do enclosure
// TODO: enable OTA updates?

enum class UltrasonicMode : int
{
  LedControl,
  SetThreshold,
  FinishSetThreshold
};

/*** STATIC PROTOTYPES ***/
// Tasks
static void
us_ranging_task(void*);
static void
hmi_task(void*);
static void
led_flash_task(void*);

static void set_thresh_dist_completed_cb(TimerHandle_t);

/*** GLOBAL VARIABLES ***/
static const char* TAG = "main.cpp";

static TaskHandle_t ghRangeTask = NULL;
static TaskHandle_t ghHmiTask = NULL;
static TaskHandle_t ghLedFlashTask = NULL;

static StaticQueue<Event, EVENT_QUEUE_COUNT> eventq;
static DebouncedButton btn{ CONFIG_BTN_PIN1, GpioPullDirection::Up };
static HCSR04 hcsr04; // Ultrasonic ranging peripheral.
static HandDetectionFilter<float,
                           HAND_DEFAULT_DIST_THRESH_CM,
                           HAND_SAMPLE_WINDOW_SIZE,
                           HAND_VALID_SAMPLES_NEEDED,
                           HAND_DEBOUNCE_PERIOD_MS>
  range_filter;
static RingBuffer<float, HAND_THRESH_SET_BUFSIZE> thresh_set_buf;
static Led led{ CONFIG_LED_CTRL_PIN };
static StaticTimer<HAND_THRESH_SET_DURATION_MS, set_thresh_dist_completed_cb>
  set_thresh_dist_timer{ "timer1" };
static DipSwitches dip;

static std::atomic<UltrasonicMode> gRangingMode = UltrasonicMode::LedControl;
static std::atomic<bool> gSensorObstructed = false;
static std::atomic<bool> gEnableFlash = false;

extern "C" void
app_main(void)
{
#ifdef TEST_FAKE_DIP_SWITCHES
  dip.enable_led_pwm = true;
  // dip.enable_led_shutoff_timeout = false;
  // dip.enable_grocery_detection = false;
#else
  read_dip_values(&dip);
#endif // TEST_FAKE_DIP_SWITCHES

  eventq.init();
  led.init(dip.enable_led_pwm);
  led.safety_timeout_enabled = dip.enable_led_shutoff_timeout;

  set_thresh_dist_timer.init();

  btn.init();
  btn.max_multi_clicks = 1; // for bmode 0

  freertos_error_check_abort(xTaskCreatePinnedToCore(us_ranging_task,
                                                     "ultrasonic-loop",
                                                     4096 * 2,
                                                     NULL,
                                                     ULTRASONIC_TASK_PRIORITY,
                                                     &ghRangeTask,
                                                     ULTRASONIC_TASK_CORE_ID),
                             TAG,
                             "create us_ranging_task");

  freertos_error_check_abort(xTaskCreatePinnedToCore(hmi_task,
                                                     "hmi-loop",
                                                     4096 * 2,
                                                     NULL,
                                                     HMI_LOOP_TASK_PRIORITY,
                                                     &ghHmiTask,
                                                     HMI_TASK_CORE_ID),
                             TAG,
                             "create hmi_task");

  freertos_error_check_abort(
    xTaskCreate(
      led_flash_task, "led_flash_task", 4096, NULL, 12, &ghLedFlashTask),
    TAG,
    "create led_flash_task");

  return;

  // For debugging purposes.
  esp_intr_dump(NULL);
}

void
sample_button(TickType_t ticks)
{
  static const char* tag = "BTN";
  static int bmode = 0;

  // --- PROCESS BUTTON ---
  switch (btn.sample(ticks)) {
    case BUTTON_EVT_LONG_PRESS:
      ESP_LOGD(tag, "changing button mode: %d", bmode);
      bmode = !bmode;
      btn.max_multi_clicks = bmode ? 4 : 1;
      eventq.send(Event::CHIRP_DOUBLE);
      break;

    case 1:
      // Re-enable normal led control of ultrsonic sensor.
      gSensorObstructed = false;

      if (bmode == 0) {
        eventq.send(Event::CYCLE_BRIGHTNESS);
      } else if (bmode == 1) {
        eventq.send(Event::TOGGLE_LED);
      }
      break;

    case 4:
      eventq.send(Event::START_SET_THRESHOLD_DISTANCE);
      break;

    default:
      break;
  }
}

static void
hmi_task(void* pvParameter)
{
  const char* tag = "HMI";

  RingBuffer<float, 8> led_bright_values;
  for (auto x : { 0.0, 0.05, 0.10, 0.20, 0.40, 0.60, 0.80, 1.0 }) {
    led_bright_values.push(x);
  }

  Event event;

  while (true) {
    auto ticks = xTaskGetTickCount();

    led.check_safety_timeout(ticks);

    sample_button(ticks);

    // Not using LED timouts at the moment.
    // led.update_timeout_tick();

    // Process global events.
    if (eventq.receive(event, 0)) {
      switch (event) {

        case Event::TOGGLE_LED:
          led.toggle();
          break;

        case Event::RESUME_LED:
          led.resume();
          break;

        case Event::CYCLE_BRIGHTNESS: {
          if (led.pwm_enabled) {
            auto bright = led_bright_values.next();
            // Notify user max brightness reached.
            if (bright == 1.0f) {
              eventq.send(Event::CHIRP_SINGLE);
            }
            led.set_brightness_user(bright);
          } else {
            led.toggle();
          }
          break;
        }

        case Event::START_SET_THRESHOLD_DISTANCE:
          ESP_LOGD(TAG, "begin calibration");
          gRangingMode = UltrasonicMode::SetThreshold;
          vTaskResume(ghLedFlashTask);
          set_thresh_dist_timer.restart();
          break;

        case Event::CHIRP_SINGLE:
          led.pulse(1, 150, 50);
          vTaskDelay(pdMS_TO_TICKS(50));
          led.resume();
          break;
        case Event::CHIRP_DOUBLE:
          if (led.pwm_enabled) {
            led.pulse(2, 150, 50);
            vTaskDelay(pdMS_TO_TICKS(50));
          } else {
            led.toggle();
            vTaskDelay(pdMS_TO_TICKS(1000));
            led.toggle();
          }
          led.resume();
          break;
      }
    }

    vTaskDelayUntil(&ticks, pdMS_TO_TICKS(1));
  }
}

static void
led_flash_task(void* pvParameter)
{
  vTaskSuspend(NULL);

  while (true) {
    led.set_brightness(1.0f);
    vTaskDelay(1000);
    led.set_brightness(0.0f);
    vTaskDelay(500);
  }
}

static void
us_ranging_task(void* pvParameter)
{
  (void)pvParameter; // not used

  const char* tag = "ultra";

  hcsr04.init(
    CONFIG_US_TRIG_PIN, CONFIG_US_ECHO_PIN, xTaskGetCurrentTaskHandle(), 0);

  while (true) {

    float dist = hcsr04.range_and_wait();

    auto ticks = xTaskGetTickCount();

    switch (gRangingMode) {
      case UltrasonicMode::LedControl:
        switch (range_filter.process_sample(dist, ticks)) {
          case HandEvent::ENTER:
            if (!gSensorObstructed) {
              eventq.send(Event::TOGGLE_LED);
            }
            break;
          case HandEvent::OBSTRUCTED:
            // A button press shall reset this.
            if (dip.enable_grocery_detection) {
              gSensorObstructed = true;
            }
            break;
          default:
            break;
        }
        break;

      case UltrasonicMode::SetThreshold:
        // Add samples to ring buffer for the window average.
        thresh_set_buf.push(dist);

        // Slow down measurements so my buffer is meaningfull.
        vTaskDelay(pdMS_TO_TICKS(HAND_THRESH_SET_SAMPLE_INTERVAL_MS));
        break;

      // Process and accept the new setp.
      case UltrasonicMode::FinishSetThreshold: {
        gRangingMode = UltrasonicMode::LedControl;

        auto& buf = thresh_set_buf.buf;
        float avg = std::accumulate(buf.begin(), buf.end(), 0.0) / buf.size();
        range_filter.set_threshold(avg);
        ESP_LOGI(tag, "New hand threshold setp: %.2fcm", avg);

        vTaskSuspend(ghLedFlashTask);
        eventq.send(Event::RESUME_LED);
        break;
      }
      default:
        break;
    }
#ifdef TESTING_SLOW_ULTRASONIC_POLLING_PERIOD
    ESP_LOGI(tag, "Range: %.2f", dist);
    vTaskDelayUntil(&ticks,
                    pdMS_TO_TICKS(TESTING_SLOW_ULTRASONIC_POLLING_PERIOD));
#endif // TESTING_SLOW_ULTRASONIC_POLLING_PERIOD
  }

  // Normally unreachable.
  vTaskDelete(NULL);
}

void
set_thresh_dist_completed_cb(TimerHandle_t xTimer)
{
  // TODO: fix ugly and poorly timed light flashing at end of threshold set
  gRangingMode = UltrasonicMode::FinishSetThreshold;
}

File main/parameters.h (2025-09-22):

#pragma once

#include "driver/gpio.h"

#include "util.h"

#define HMI_POLLING_PERIOD_MS 1
#define EVENT_QUEUE_COUNT     5

#define CONFIG_US_STARTING_DELAY_BETWEEN_RANGES_MS 3

#define HAND_DEFAULT_DIST_THRESH_CM 10.0f
#define HAND_SAMPLE_WINDOW_SIZE     5
#define HAND_VALID_SAMPLES_NEEDED   4
#define HAND_DEBOUNCE_PERIOD_MS     300

// Total time the unit will spend in the threshold set mode.
#define HAND_THRESH_SET_DURATION_MS        SECONDS_TO_MS(5)
#define HAND_THRESH_SET_SAMPLE_INTERVAL_MS 50
#define HAND_THRESH_SET_BUFSIZE            20

static_assert((HAND_THRESH_SET_SAMPLE_INTERVAL_MS * HAND_THRESH_SET_BUFSIZE *
               4) < HAND_THRESH_SET_DURATION_MS,
              "Buffer may be too large for accurate sample averaging.");

// How long the hand must remain still for the threshold distance to be
// accepted.
#define HAND_THRESH_SET_AVG_WINDOW_MS 3 * 1000

#define LED_PWM_FREQ_HZ        (40 * 1000)
#define LED_WARNING_TIMEOUT_MS MINUTES_TO_MS(120)
#define LED_SHUTOFF_TIMEOUT_MS (LED_WARNING_TIMEOUT_MS + MINUTES_TO_MS(10))

// ------------------------
// Board Selection
// ------------------------
#define MODULE_QTPY_ESP32_S3_PROTOTYPE_1

#ifdef MODULE_QTPY_ESP32_S3_PROTOTYPE_1
#define CONFIG_HAS_ROTARY_ENCODER_V1
#define CONFIG_LED_CTRL_PIN   GPIO_NUM_18
#define CONFIG_ROTARY_PIN_BTN GPIO_NUM_17
#define CONFIG_ROTARY_PIN_A   GPIO_NUM_8
#define CONFIG_ROTARY_PIN_B   GPIO_NUM_9
#define CONFIG_US_TRIG_PIN    GPIO_NUM_16
#define CONFIG_US_ECHO_PIN    GPIO_NUM_5
#define CONFIG_BTN_PIN1       GPIO_NUM_0 // Internal btn on mcu.
#endif                                   // MODULE_QTPY_ESP32_S3_PROTOTYPE_1

#ifdef MODULE_QTPY_ESP32_S3_PROTOTYPE_2
#define CONFIG_LED_CTRL_PIN GPIO_NUM_18
#define CONFIG_US_TRIG_PIN  GPIO_NUM_16
#define CONFIG_US_ECHO_PIN  GPIO_NUM_5
#define CONFIG_BTN_PIN1     GPIO_NUM_0
#define CONFIG_HAS_DIP_SWITCH_V1
#define DIP_ENABLE_LED_PWM_PIN             GPIO_NUM_6
#define DIP_ENABLE_LED_SHUTOFF_TIMEOUT_PIN GPIO_NUM_7
#define DIP_ENABLE_GROCERY_DETECT_PIN      GPIO_NUM_8
#endif // MODULE_QTPY_ESP32_S3_PROTOTYPE_1

// TASK PRIORITIES
// ESP32 has 25 task priorities. (0-24). Higher number means higher priority.
#define ESP32_MAX_PRIORITY configMAX_PRIORITIES - 1
static_assert(ESP32_MAX_PRIORITY <= 24);
#define ULTRASONIC_TASK_PRIORITY 24
#define HMI_LOOP_TASK_PRIORITY   5
#define ULTRASONIC_TASK_CORE_ID  0
#define HMI_TASK_CORE_ID         1

/*** TESTING DEFINES ***/
// #define TESTING_SLOW_ULTRASONIC_POLLING_PERIOD 750
#define TEST_FAKE_DIP_SWITCHES

// TODO: check task stats with vTaskGetRunTimeStats(char *pcWriteBuffer)
// Use a buffer of >40 characters

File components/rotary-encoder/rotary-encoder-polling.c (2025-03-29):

#include "rotary-encoder-polling.h"

#include <stdbool.h>
#include <stdint.h>
#include <stdlib.h>
#include <string.h>

#include "driver/gpio.h"
#include "driver/pulse_cnt.h"
#include "esp_attr.h"
#include "esp_log.h"
#include "sdkconfig.h"

static const char* TAG = "encoder";

static bool IRAM_ATTR
pcnt_on_reach(pcnt_unit_handle_t unit,
              const pcnt_watch_event_data_t* edata,
              void* pvParameter)
{

  re_polling_rotary_encoder_t* encoder =
    (re_polling_rotary_encoder_t*)pvParameter;
  encoder->previous_pulse_count = 0;
  if (encoder->pcnt_unit) {
    pcnt_unit_clear_count(encoder->pcnt_unit);
  }

  // Don't return to a higher priority task.
  return false;
}

// Pulses may be missed during rollover if high and low limit or set above or
// below the maximum and minimum values of a 16-bit integer.
bool
rep_initialize(re_polling_rotary_encoder_t* this)
{
  // High and low limit of the internal pulse value register.
  // I use the full 16-bit register provided by ESP32 and handle the user
  // counter/position in a software check.
  const int high_limit = INT16_MAX;
  const int low_limit = INT16_MIN;

  ESP_LOGI(TAG, "Initializing counter.");

  pcnt_unit_config_t unit_config = { .high_limit = high_limit,
                                     .low_limit = low_limit,
                                     .flags.accum_count = 1 };
  pcnt_unit_handle_t pcnt_unit = NULL;
  ESP_ERROR_CHECK(pcnt_new_unit(&unit_config, &pcnt_unit));

  pcnt_glitch_filter_config_t filter_config = {
    .max_glitch_ns = this->min_pulse_duration_ns,
  };
  ESP_ERROR_CHECK(pcnt_unit_set_glitch_filter(pcnt_unit, &filter_config));

  /*
   * Quadrature rotary encoder typical signal:
   * Note that this diagram and some data sheets have the convention the signal
   * will be pulled low when 'ON'.
   *
   * A      +-----+     +-----+     +-----+
   *          OFF |     |     |     |
   *              |  ON |     |     |
   *              +-----+     +-----+
   * B         +-----+     +-----+     +-----+
   *                 |     |     |     |
   *                 |     |     |     |
   *                 +-----+     +-----+
   *
   *  +--------------------------------------->
   *                 CW direction
   */

  // level_gpio_num is the control signal
  pcnt_chan_config_t chan_a_config = {
    .edge_gpio_num = this->pinA,
    .level_gpio_num = this->pinB,
  };
  pcnt_channel_handle_t pcnt_chan_a = NULL;

  ESP_ERROR_CHECK(pcnt_new_channel(pcnt_unit, &chan_a_config, &pcnt_chan_a));

  // When pin A gets pulled low (while B is high), increase the value.
  // When pin A gets pulled low (while B is low), decrease the value.
  ESP_ERROR_CHECK(
    pcnt_channel_set_edge_action(pcnt_chan_a,
                                 PCNT_CHANNEL_EDGE_ACTION_INCREASE,
                                 PCNT_CHANNEL_EDGE_ACTION_DECREASE));
  ESP_ERROR_CHECK(
    pcnt_channel_set_level_action(pcnt_chan_a,
                                  PCNT_CHANNEL_LEVEL_ACTION_KEEP,
                                  PCNT_CHANNEL_LEVEL_ACTION_INVERSE));

  // When pin B gets pulled low (while A is high), decrease the value.
  // When pin B gets pulled low (while A is low), increase the value.
  pcnt_chan_config_t chan_b_config = {
    .edge_gpio_num = this->pinB,
    .level_gpio_num = this->pinA,
  };

  pcnt_channel_handle_t pcnt_chan_b = NULL;

  ESP_ERROR_CHECK(pcnt_new_channel(pcnt_unit, &chan_b_config, &pcnt_chan_b));

  ESP_ERROR_CHECK(
    pcnt_channel_set_edge_action(pcnt_chan_b,
                                 PCNT_CHANNEL_EDGE_ACTION_INCREASE,
                                 PCNT_CHANNEL_EDGE_ACTION_DECREASE));
  ESP_ERROR_CHECK(
    pcnt_channel_set_level_action(pcnt_chan_b,
                                  PCNT_CHANNEL_LEVEL_ACTION_INVERSE,
                                  PCNT_CHANNEL_LEVEL_ACTION_KEEP));

  // Trigger a callback before counter rolls over.
  ESP_ERROR_CHECK(pcnt_unit_add_watch_point(pcnt_unit, high_limit));
  ESP_ERROR_CHECK(pcnt_unit_add_watch_point(pcnt_unit, low_limit));

  pcnt_event_callbacks_t cbs = {
    .on_reach = pcnt_on_reach,
  };

  ESP_ERROR_CHECK(pcnt_unit_register_event_callbacks(pcnt_unit, &cbs, this));
  ESP_ERROR_CHECK(pcnt_unit_enable(pcnt_unit));
  ESP_ERROR_CHECK(pcnt_unit_clear_count(pcnt_unit));
  ESP_ERROR_CHECK(pcnt_unit_start(pcnt_unit));

  this->pcnt_unit = pcnt_unit;
  this->value = 0;
  this->previous_pulse_count = 0;

  return true;
}

void
rep_reset(re_polling_rotary_encoder_t* this)
{
  // Add lock here if using a multithreaded environment
  this->previous_pulse_count = 0;
  this->value = 0;
  this->changed = true;
  ESP_ERROR_CHECK(pcnt_unit_clear_count(this->pcnt_unit));
}

re_count_t
rep_get_value(re_polling_rotary_encoder_t* this)
{
  return this->value;
}

re_count_t
rep_get_delta(re_polling_rotary_encoder_t* this)
{

  return this->delta;
}

/**
 * Returns true if the value was changed since it was last checked.
 */
bool
rep_sample(re_polling_rotary_encoder_t* this)
{
  int pulse_count = 0;

  ESP_ERROR_CHECK(pcnt_unit_get_count(this->pcnt_unit, &pulse_count));

  // Number of state changes, with direction.
  int delta = (pulse_count - this->previous_pulse_count) / 4;

  // Only change the value for a full quadrature signal, i.e 4 pulses
  // The ESP32S3 has an abs machine instruction. Nice!
  if (abs(delta) > 0) {
    this->previous_pulse_count += delta * 4;
    this->delta = delta;

    // Prevent the value from going over our max or under our min.
    const bool overflow = (this->value >= this->max) && delta > 0;
    const bool underflow = (this->value <= this->min) && delta < 0;

    if (!(overflow) && !(underflow)) {
      this->value += delta;
    }

    return true;
  }

  // This is to handle other threads calling 'set_value' in between samples.
  // In this case there would be no delta between the previous pulse count and
  // the current pulse count to indicate a change.
  if (this->changed) {
    this->changed = false;
    return true;
  }

  return false;
}

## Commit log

2024-08-29 initial commit - working HC-SR04, LVGL, Rotary Encoder, and Button
    [code-format.cfg]
2024-09-02 working LEDC basic driver
2024-09-02 make led dimmable from rotary encoder input
2024-09-02 add timmout dimmer to ledc
2024-09-02 move disp pdf to spi library
2024-09-10 create board layout in kicad
    [AISLER-2Layer.kicad_pcb, AISLER-2Layer.sch, AISLER-4Layer.kicad_pcb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]
2024-09-21 update board layout
    [Adafruit QT Py ESP32-S3.kicad_pcb, Adafruit QT Py ESP32-S3.kicad_sch, cablight.kicad_pcb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]
2024-09-22 pcb board review
    [cablight.kicad_pcb, cablight.kicad_sch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]
2024-09-30 board updates
    [PEC11-5mm.step, QTPy.step, RCWL-1601.step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]
2024-09-30 restructure folders
    [AISLER-2Layer.kicad_pcb, AISLER-2Layer.sch, AISLER-4Layer.kicad_pcb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]
2024-10-17 archive kiCAD project
2024-10-17 remove gui
    [code-format.cfg]
2024-11-06 remove eventq and fix warnings
    [led.hpp, main.cpp, ultrasonic.cpp]
2024-11-06 ignore kicad backups
2024-11-12 add enable flag for led timeout & warning
2025-09-15 Add Button code support and make ultrasonic notify from task.
    [cablight-project v2.step, cablight-project v2.stl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]
2025-09-16 create esp & freertos error check functions
    [main.cpp]
2025-09-16 put gpio init in button init func
2025-09-19 add DIP switch to kicad
    [cablight-project.kicad_pcb, cablight-project.kicad_sch]
2025-10-01 Layout KiCAD for DIP switches and button.
    [cablight-project-B_Cu.gbl, cablight-project-B_Mask.gbs, cablight-project-B_Paste.gbp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]
2025-10-06 submit board v2
2025-10-06 remove 4th dip switch
2025-11-11 add kicad to gitignore

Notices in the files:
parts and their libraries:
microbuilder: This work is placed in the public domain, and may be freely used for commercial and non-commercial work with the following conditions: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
